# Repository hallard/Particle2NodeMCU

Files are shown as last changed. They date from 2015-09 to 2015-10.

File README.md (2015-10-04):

Particle Spark/Photon to NodeMCU Adapter
========================================

This adapter is used to put in place of a Spark/Photon a NodeMCU board with ESP8266 I needed for a specific French [project][3]. I needed SPI for RFM69 Module with IRQ on ~~GPIO2~~ GPIO15 and SS on GPIO2 (see below why).
I choosed NodeMCU boards instead of ESP8266 because NodeMCU has all I needed on board, such as pullups, switches, USB power, 3/3V regulator, USB2Serial...

Since ESP8266 has less pin than Particle boards, only "classic" have been connected

- SPI Interface (GPIO12 to 14) GPIO15 is used for RFM69 IRQ
- I2C Interface (GPIO14 and GPIO5)
- Serial (GPIO1 and GPIO3)
- GPIO0 as free I/O (Flash button on NodeMCU)
- GPIO2 is used as Chip Select (SS) for RFM69
- GPIO16 as free I/O (LED and KEY on NodeMCU)

I discovered some issue with 1st design, see below :
- ESP8266 to boot correctly needs some pins at defined level, GPIO15 must be LOW and GPIO2 must be HIGH. Unfortunatlly with RFM69 connected as IRQ to GPIO2 and SS to GPIO15 it does not boot because RF69 pull it DIO IRQ to LOW, making GPIO2 LOW and ESP8266 not booting. The fix is to reverse the wiring, connect IRQ to GPIO15 and SS to GPIO2 (and do according changes in the code). 
- Teleinfo had some issue due to NodeMCU USB/Serial onboard converter that was in conflict and was killing RX signal coming from optocoupler. To avoid this I've put 2 inverters to have a correct RX Teleinfo signal coming to EMP8266. No Risk because on board RX Signal of NodeMCU has a 470 Ohm resistor in serial of this line. To avoid this may be we could use a ESP8266 without any USB/Serial adapteur such as a Adafruit [Huzzah][5] or Olimex [ESP8266 Dev][6]
- it really just to fit board adapter on Remora if you have the big relay installed, it fits but it's really really close, so in version 1.1a, I just moved a little bit the adapter from the board relay.
- to be able to handle future Remora PCB version I added the feature to enable/disable Téléinfo FET Staging (they will already be placed on Remora V1.3 PCB) using Jumper J1 & J2.

This page has been updated to reflect the changes and the PCB also, it's now v1.1a.   

*Boards are still in progress, I did not fully tested them yet, I will update as soon has I got them in my hands. Use at your own risks*

Detailed Description
====================

Look at the schematics for more informations.

### Schematic  
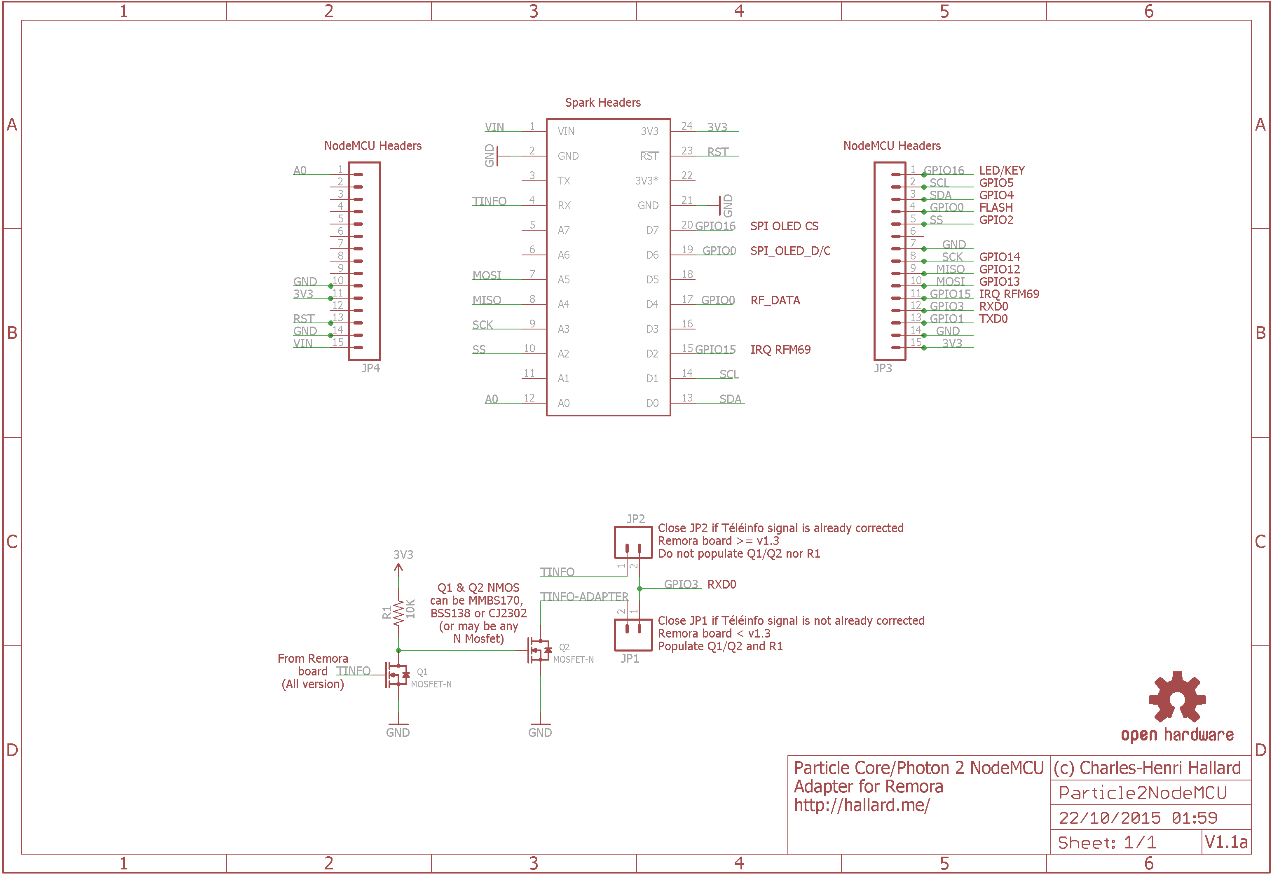
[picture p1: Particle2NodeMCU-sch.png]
schematic
  

### Boards  
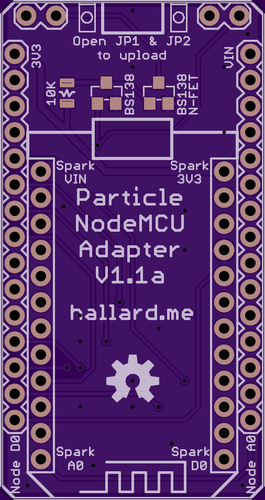
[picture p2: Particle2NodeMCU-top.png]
&nbsp;
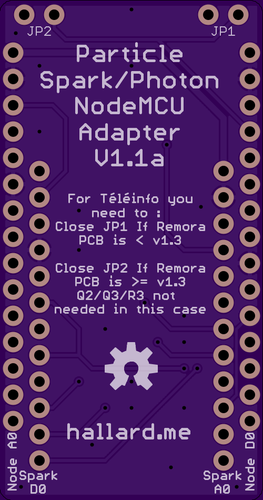
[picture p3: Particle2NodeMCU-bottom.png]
Bottom
&nbsp; 

If you have old version V1.0 PCB and a RFM69 attached, here the fix, cut line in red and solder wire on green line.   

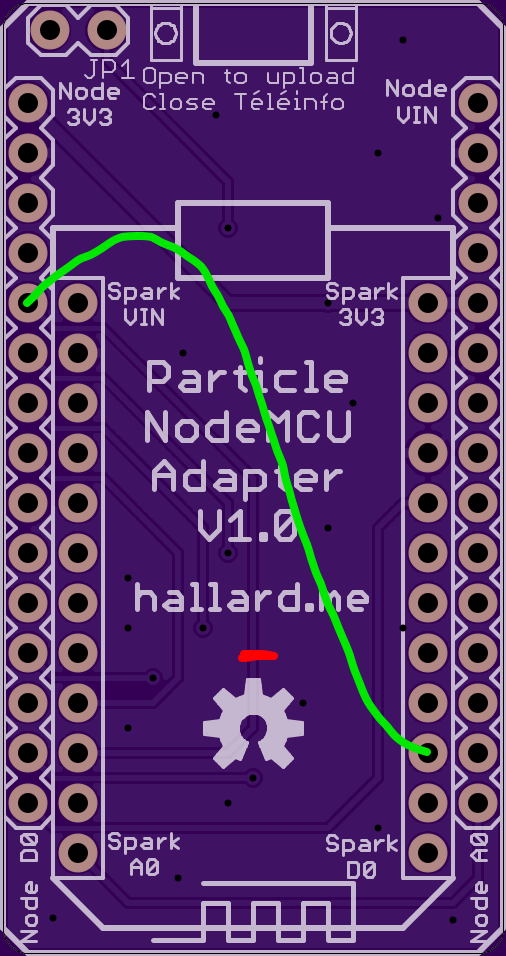
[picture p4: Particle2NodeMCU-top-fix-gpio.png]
&nbsp;
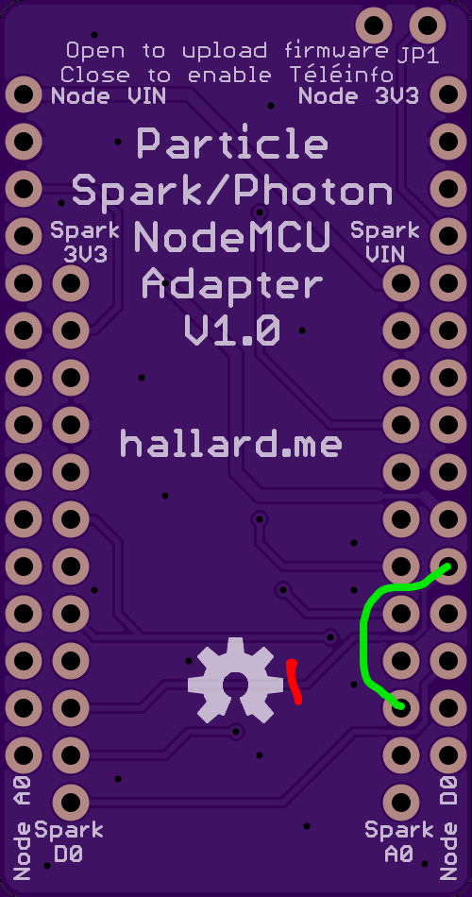
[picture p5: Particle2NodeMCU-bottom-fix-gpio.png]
Bottom
&nbsp; 

You can order the PCB of this board v1.1a at [OSHPARK][4]

### Assembled boards

~~I'm currently waiting for boards from OSHPARK~~
Boards arrived, still testing before ordering V1.1a boards

##License

You can do whatever you like with this design.

##Misc
See news and other projects on my [blog][2] 
 
[2]: https://hallard.me
[3]: https://github.com/thibdct/programmateur-fil-pilote-wifi/tree/master/Logiciel/remora
[4]: https://oshpark.com/shared_projects/jYm6pI7a
[5]: https://www.adafruit.com/product/2471
[6]: https://www.olimex.com/Products/IoT/MOD-WIFI-ESP8266-DEV/

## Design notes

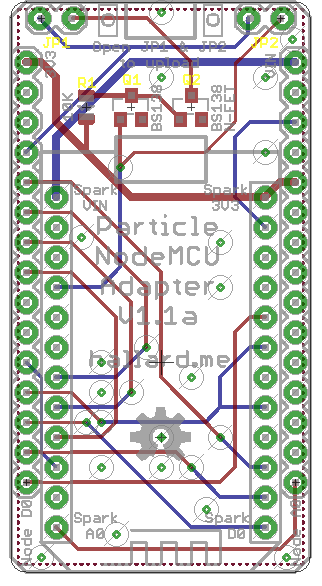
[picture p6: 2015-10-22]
Particle2NodeMCU-brd.png

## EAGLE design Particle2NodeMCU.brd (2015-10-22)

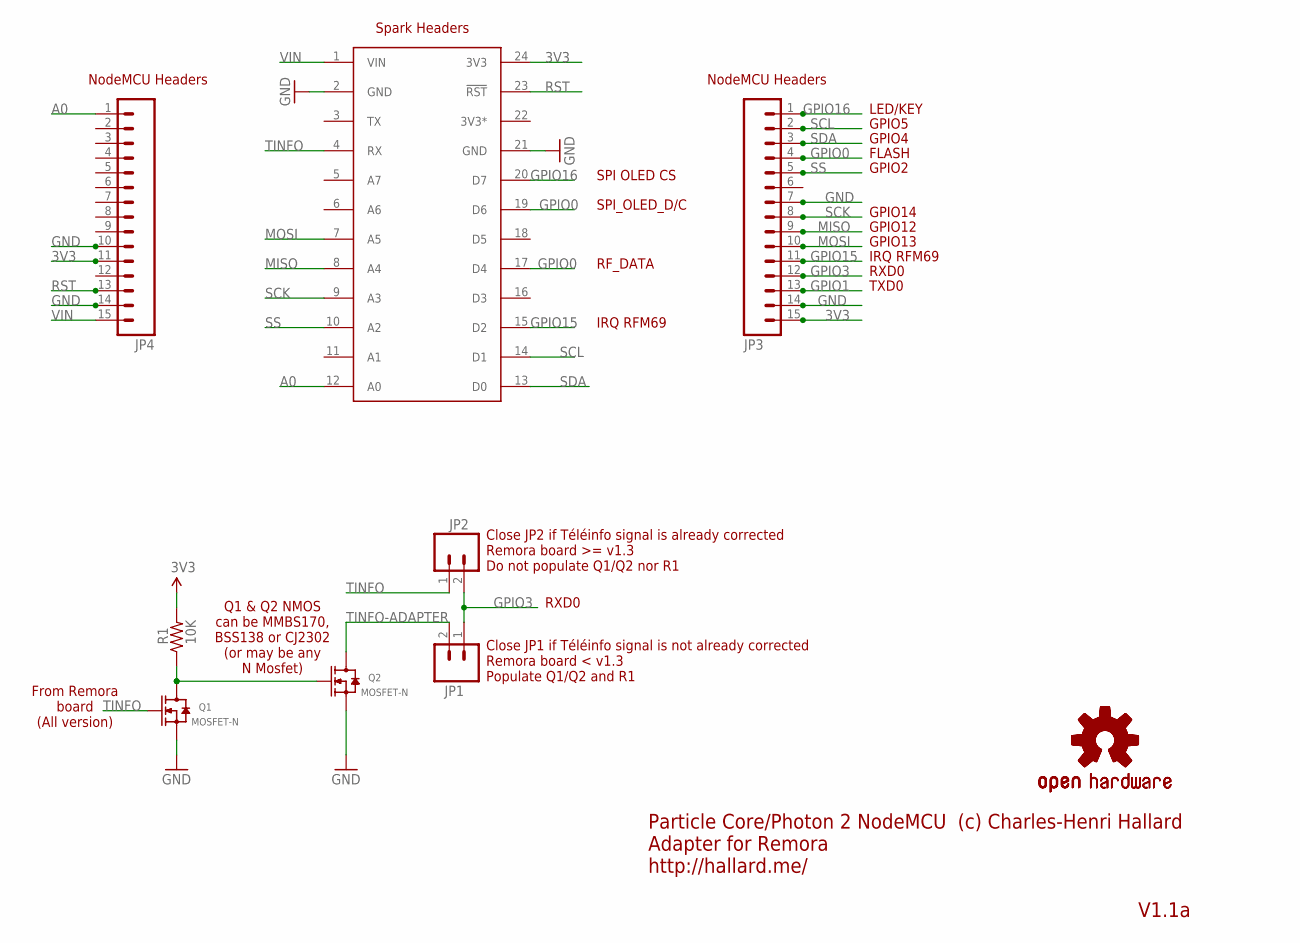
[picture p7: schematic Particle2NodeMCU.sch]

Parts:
JP1, JP2: M02LOCK; 1X02_LOCK
JP3, JP4: M15; 1X15
LOGO1, LOGO2: OSHW-LOGOM; OSHW-LOGO-M
Q1, Q2: MOSFET-N; SOT23
R1: 10K; 0805-RES
U$2: SPARK_CORECORE; SPARK_CORE

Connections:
3V3: JP3.15, JP4.11, R1.2, U$2.24 (3V3)
3V3*: U$2.22 (3V3*)
A0: JP4.1, U$2.12 (A0)
GND: JP3.7, JP3.14, JP4.10, JP4.14, Q1.2 (S), Q2.2 (S), U$2.2 (GND), U$2.21 (GND)
GPIO0: JP3.4, U$2.17 (D4), U$2.19 (D6)
GPIO1: JP3.13
GPIO3: JP1.1, JP2.2, JP3.12
GPIO15: JP3.11, U$2.15 (D2)
GPIO16: JP3.1, U$2.20 (D7)
MISO: JP3.9, U$2.8 (A4)
MOSI: JP3.10, U$2.7 (A5)
unnamed: Q1.3 (D), Q2.1 (G), R1.1
RST: JP4.13, U$2.23 (!RST)
SCK: JP3.8, U$2.9 (A3)
SCL: JP3.2, U$2.14 (D1)
SDA: JP3.3, U$2.13 (D0)
SS: JP3.5, U$2.10 (A2)
TINFO: JP2.1, Q1.1 (G), U$2.4 (RX)
TINFO-ADAPTER: JP1.2, Q2.3 (D)
VIN: JP4.15, U$2.1 (VIN)

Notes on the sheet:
IRQ RFM69
FLASH
GPIO12
GPIO4
GPIO5
RXD0
TXD0
GPIO13
GPIO14
GPIO2
LED/KEY
NodeMCU Headers
SPI_OLED_D/C
SPI OLED CS
RF_DATA
Spark Headers
Particle Core/Photon 2 NodeMCU Adapter for Remora http://hallard.me/
(c) Charles-Henri Hallard
V1.1a
Q1 & Q2 NMOS can be MMBS170, BSS138 or CJ2302 (or may be any N Mosfet)
Close JP1 if Téléinfo signal is not already corrected Remora board < v1.3 Populate Q1/Q2 and R1
Close JP2 if Téléinfo signal is already corrected Remora board >= v1.3 Do not populate Q1/Q2 nor R1
From Remora board (All version)

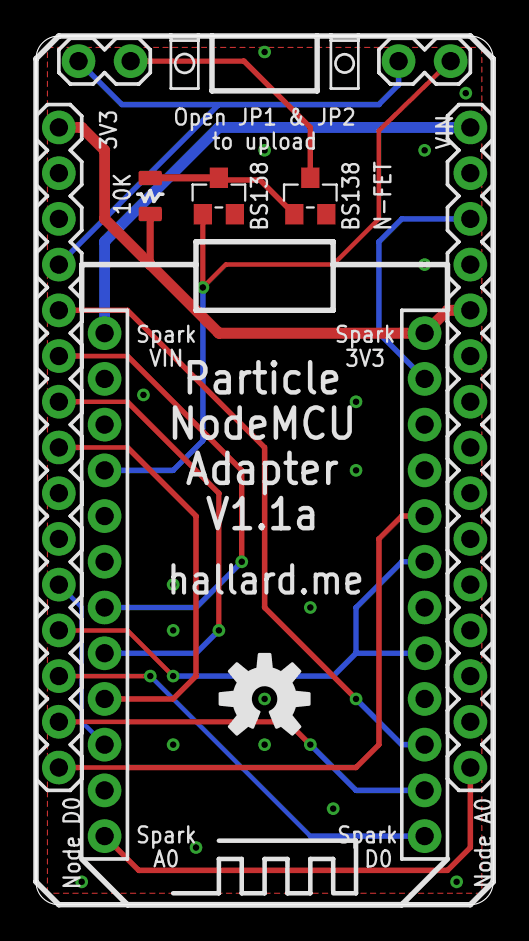
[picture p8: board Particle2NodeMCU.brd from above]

Board: 2 copper layers, 25.4 x 48.3 mm, 10 parts (1 on the bottom side), 18 nets.

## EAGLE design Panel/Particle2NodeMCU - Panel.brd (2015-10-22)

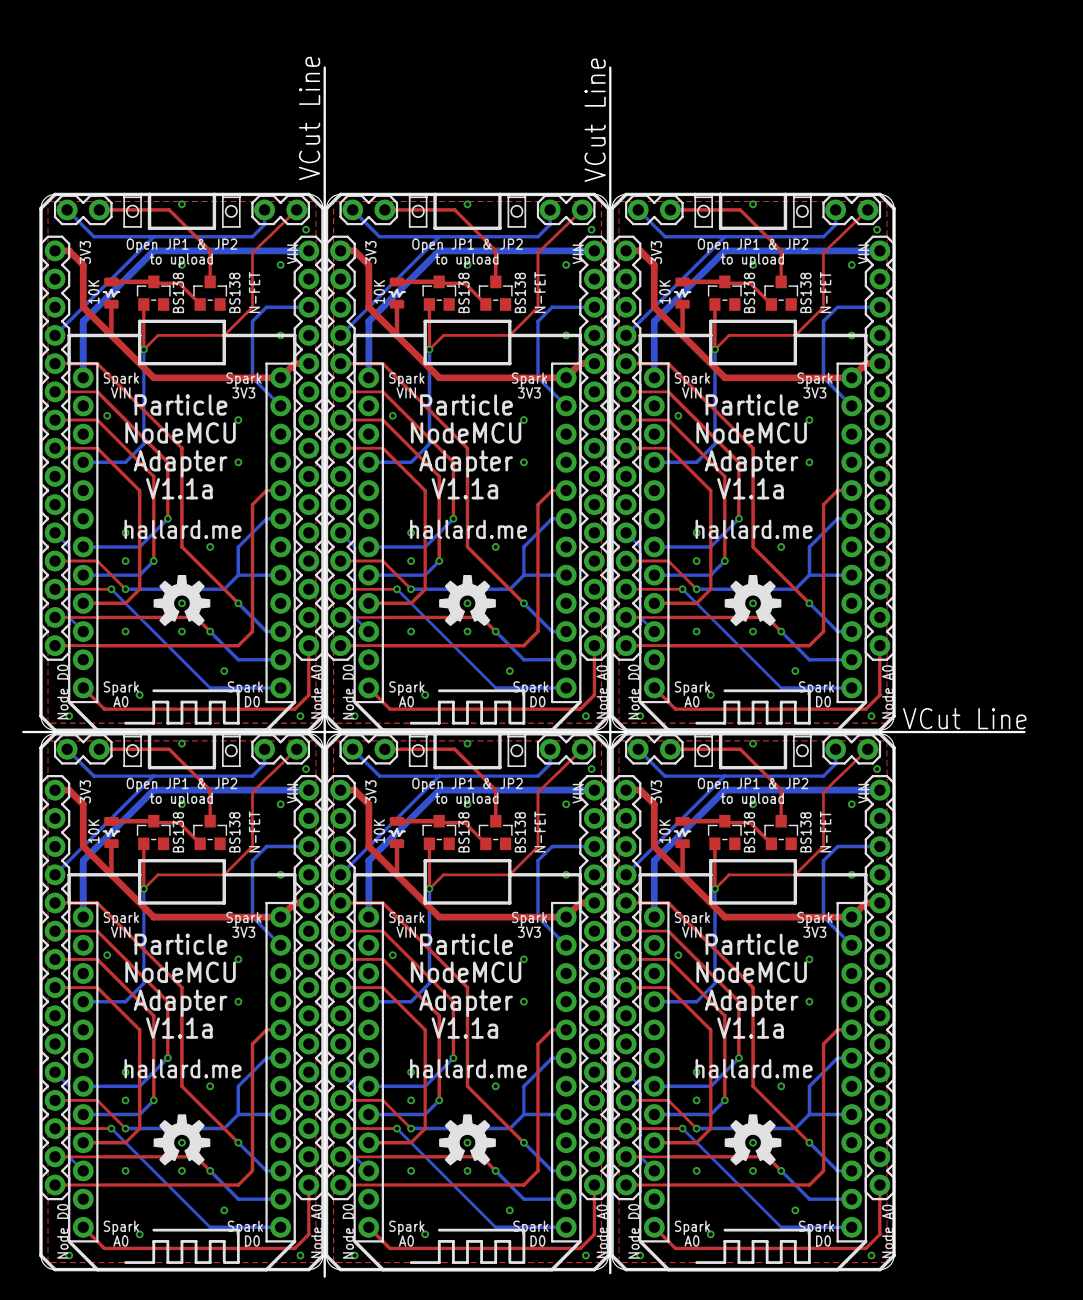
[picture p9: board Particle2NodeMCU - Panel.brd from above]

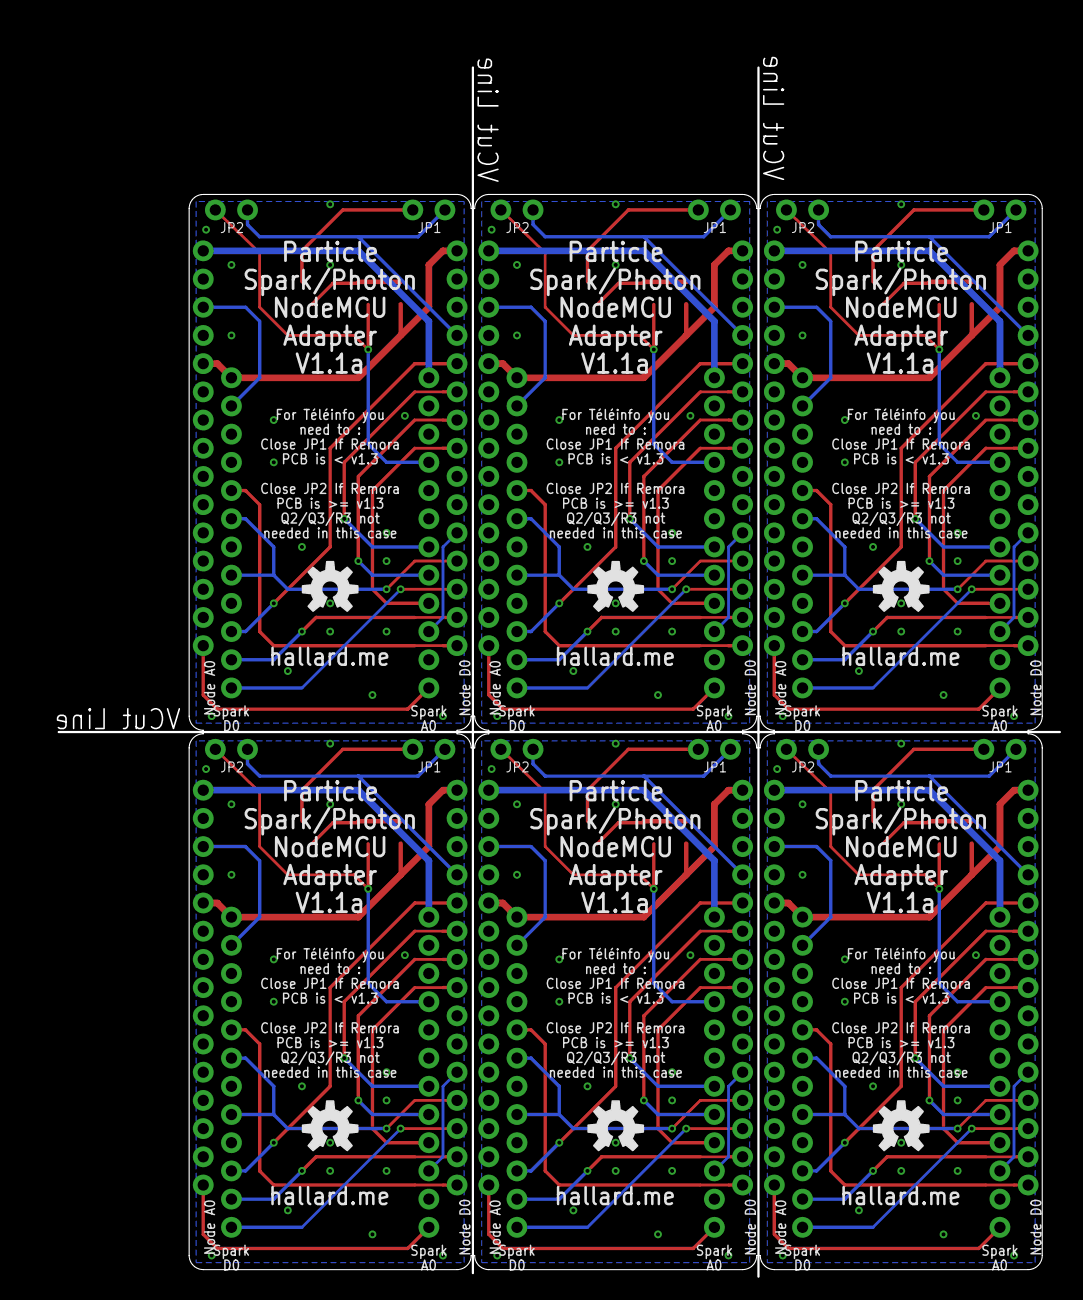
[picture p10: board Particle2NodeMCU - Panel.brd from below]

Board: 2 copper layers, 76.8 x 96.8 mm, 60 parts (6 on the bottom side), 108 nets.

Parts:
JP1, JP2, JP5, JP8, JP9, JP12, JP13, JP16, JP17, JP20, JP21, JP24: 1X02_LOCK
JP3, JP4, JP6, JP7, JP10, JP11, JP14, JP15, JP18, JP19, JP22, JP23: 1X15
LOGO1, LOGO2, LOGO3, LOGO4, LOGO5, LOGO6, LOGO7, LOGO8, LOGO9, LOGO10, LOGO11, LOGO12: OSHW-LOGOM; OSHW-LOGO-M
Q1, Q2, Q3, Q4, Q5, Q6, Q7, Q8, Q9, Q10, Q11, Q12: MOSFET-N; SOT23
R1, R2, R3, R4, R5, R6: 10K; 0805-RES
U$1, U$2, U$3, U$4, U$5, U$6: SPARK_CORECORE; SPARK_CORE

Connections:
3V1: JP6.11, JP7.15, R2.2, U$1.24
3V2: JP10.11, JP11.15, R3.2, U$3.24
3V3: JP3.15, JP4.11, R1.2, U$2.24
3V4: JP14.11, JP15.15, R4.2, U$4.24
3V5: JP18.11, JP19.15, R5.2, U$5.24
3V6: JP22.11, JP23.15, R6.2, U$6.24
A0: JP4.1, U$2.12
A1: JP6.1, U$1.12
A2: JP10.1, U$3.12
A3: JP14.1, U$4.12
A4: JP18.1, U$5.12
A5: JP22.1, U$6.12
GND: JP3.7, JP3.14, JP4.10, JP4.14, Q1.2, Q2.2, U$2.2, U$2.21
GND1: JP6.10, JP6.14, JP7.7, JP7.14, Q3.2, Q4.2, U$1.2, U$1.21
GND2: JP10.10, JP10.14, JP11.7, JP11.14, Q5.2, Q6.2, U$3.2, U$3.21
GND3: JP14.10, JP14.14, JP15.7, JP15.14, Q7.2, Q8.2, U$4.2, U$4.21
GND4: JP18.10, JP18.14, JP19.7, JP19.14, Q9.2, Q10.2, U$5.2, U$5.21
GND5: JP22.10, JP22.14, JP23.7, JP23.14, Q11.2, Q12.2, U$6.2, U$6.21
GPIO0: JP3.4, U$2.17, U$2.19
GPIO2: JP7.1, U$1.20
GPIO3: JP1.1, JP2.2, JP3.12
GPIO5: JP5.1, JP7.12, JP8.2
GPIO6: JP7.11, U$1.15
GPIO7: JP7.4, U$1.17, U$1.19
GPIO8: JP11.1, U$3.20
GPIO10: JP9.1, JP11.12, JP12.2
GPIO11: JP11.11, U$3.15
GPIO12: JP11.4, U$3.17, U$3.19
GPIO13: JP15.1, U$4.20
GPIO15: JP3.11, U$2.15
GPIO16: JP3.1, U$2.20
GPIO17: JP13.1, JP15.12, JP16.2
GPIO18: JP15.11, U$4.15
GPIO19: JP15.4, U$4.17, U$4.19
GPIO20: JP19.1, U$5.20
GPIO22: JP17.1, JP19.12, JP20.2
GPIO23: JP19.11, U$5.15
GPIO24: JP19.4, U$5.17, U$5.19
GPIO25: JP23.1, U$6.20
GPIO27: JP21.1, JP23.12, JP24.2
GPIO28: JP23.11, U$6.15
GPIO29: JP23.4, U$6.17, U$6.19
MISO: JP3.9, U$2.8
MISO1: JP7.9, U$1.8
MISO2: JP11.9, U$3.8
MISO3: JP15.9, U$4.8
MISO4: JP19.9, U$5.8
MISO5: JP23.9, U$6.8
MOSI: JP3.10, U$2.7
MOSI1: JP7.10, U$1.7
MOSI2: JP11.10, U$3.7
MOSI3: JP15.10, U$4.7
MOSI4: JP19.10, U$5.7
MOSI5: JP23.10, U$6.7
unnamed: Q3.3, Q4.1, R2.1
unnamed: Q5.3, Q6.1, R3.1
unnamed: Q1.3, Q2.1, R1.1
unnamed: Q7.3, Q8.1, R4.1
unnamed: Q9.3, Q10.1, R5.1
unnamed: Q11.3, Q12.1, R6.1
RST: JP4.13, U$2.23
RST1: JP6.13, U$1.23
RST2: JP10.13, U$3.23
RST3: JP14.13, U$4.23
RST4: JP18.13, U$5.23
RST5: JP22.13, U$6.23
SCK: JP3.8, U$2.9
SCK1: JP7.8, U$1.9
SCK2: JP11.8, U$3.9
SCK3: JP15.8, U$4.9
SCK4: JP19.8, U$5.9
SCK5: JP23.8, U$6.9
SCL: JP3.2, U$2.14
SCL1: JP7.2, U$1.14
SCL2: JP11.2, U$3.14
SCL3: JP15.2, U$4.14
SCL4: JP19.2, U$5.14
SCL5: JP23.2, U$6.14
SDA: JP3.3, U$2.13
SDA1: JP7.3, U$1.13
SDA2: JP11.3, U$3.13
SDA3: JP15.3, U$4.13
SDA4: JP19.3, U$5.13
SDA5: JP23.3, U$6.13
SS: JP3.5, U$2.10
SS1: JP7.5, U$1.10
SS2: JP11.5, U$3.10
SS3: JP15.5, U$4.10
SS4: JP19.5, U$5.10
SS5: JP23.5, U$6.10
TINFO: JP2.1, Q1.1, U$2.4
TINFO1: JP8.1, Q3.1, U$1.4
TINFO2: JP12.1, Q5.1, U$3.4
TINFO3: JP16.1, Q7.1, U$4.4
TINFO4: JP20.1, Q9.1, U$5.4
TINFO5: JP24.1, Q11.1, U$6.4
TINFO-ADAPTER: JP1.2, Q2.3
TINFO-ADAPTER1: JP5.2, Q4.3
TINFO-ADAPTER2: JP9.2, Q6.3
TINFO-ADAPTER3: JP13.2, Q8.3
TINFO-ADAPTER4: JP17.2, Q10.3
TINFO-ADAPTER5: JP21.2, Q12.3
VIN: JP4.15, U$2.1
VIN1: JP6.15, U$1.1
VIN2: JP10.15, U$3.1
VIN3: JP14.15, U$4.1
VIN4: JP18.15, U$5.1
VIN5: JP22.15, U$6.1

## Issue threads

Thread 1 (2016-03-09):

Board bom file

chrigui, 2016-03-09:
Great project!!!
I just ordered 9 boards eta end of March, will be using this boards with photon weather shield.

Thanks for the great share

hallard, 2016-03-16:
@chrigui
thank for the head up

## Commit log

2015-08-27 Updated schematic picture title
2015-09-27 Fixed GPIO now version 1.0a
    [Particle2NodeMCU.brd, Particle2NodeMCU.sch]
2015-09-27 Relay fix explannation
2015-09-27 Fixed Wiring Error
2015-09-28 Version 1.1 ajout inverseur FET
    [Particle2NodeMCU.brd, Particle2NodeMCU.sch]
2015-09-28 Silk Error on R1
    [Particle2NodeMCU.brd]
2015-10-04 Updated to 1.1a
    [Particle2NodeMCU.brd, Particle2NodeMCU.sch]
2015-10-04 Approved errors
    [Particle2NodeMCU.sch]
2015-10-06 Label error on GPIO2/GPIO15
    [Particle2NodeMCU.sch]
2015-10-22 Ready To Panelize
    [Particle2NodeMCU.brd, Particle2NodeMCU.sch]
2015-10-22 Folder Reorg
    [Particle2NodeMCU - Panel.GBL, Particle2NodeMCU - Panel.GBO, Particle2NodeMCU - Panel.GBP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]

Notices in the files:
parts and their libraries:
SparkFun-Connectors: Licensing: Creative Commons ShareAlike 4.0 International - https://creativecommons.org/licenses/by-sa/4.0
